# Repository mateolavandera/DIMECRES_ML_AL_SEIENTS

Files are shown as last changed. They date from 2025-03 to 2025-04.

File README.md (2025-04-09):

View this project on [CADLAB.io](https://cadlab.io/project/28988). 

# DIMECRES_ML_AL_SEIENTS
## Autors
- Mateo Lavandera Mulet (@mateolavandera)
- Alex Lara Bailon (@AlexLB4)

## Versió - v1.0 ## Curs - Assignatura de Disseny de PCBs amb KiCad - [Curs 2024-2025]

## Objectiu Descripció breu de l'objectiu del projecte.
L’objectiu del nostre projecte és dissenyar un sistema que sigui capaç d'executar correctament les diferents funcions que controlen uns seients elèctrics d’un cotxe qualsevol.

## Requisits i especificacions
→ 3 motors (posició, alçada, reclinació) amb els seus finals de carrera. 
→ Calefacció del seient. 
→ Sensor digital de cinturons. 
→ Memòria externa no volàtil per guardar posicions preprogramades.

## Diagrama de blocs (Afegiu una imatge del diagrama de blocs)
### Tercera versió (final)
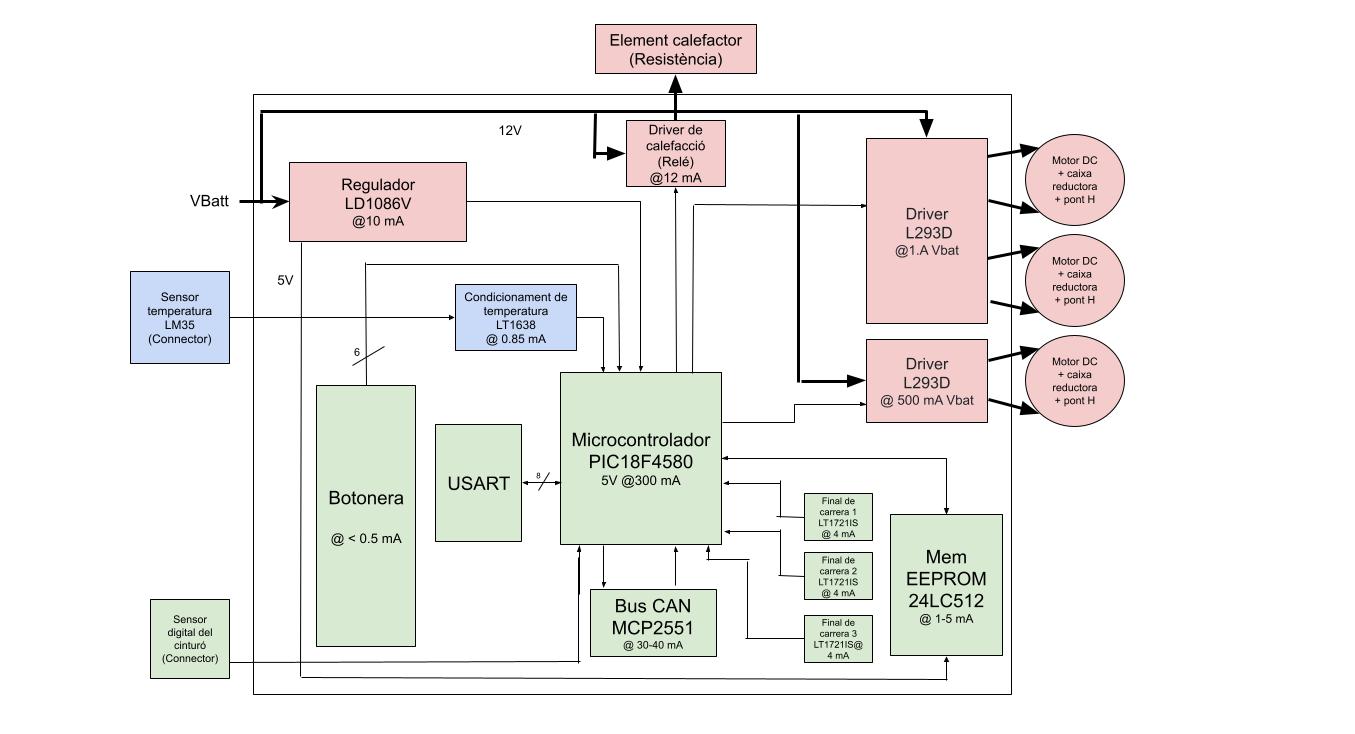
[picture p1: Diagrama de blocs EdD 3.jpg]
Diagrama de blocs


## Taula de components
| Descripció | Manufacturer Number | Package | Datasheet | Proveïdor | Unitats |
|---|---|---|---|---|---|
| Regulador Lineal 1.5 A  | LD1086V | TO-220 | [Enllaç](https://www.st.com/content/ccc/resource/technical/document/datasheet/53/db/00/58/09/98/4b/36/CD00001884.pdf/files/CD00001884.pdf/jcr:content/translations/en.CD000018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) | DigiKey | 1 |
| Microcontrolador PIC 8-bit 300mA | PIC18F4580-I/PT | 44-TQFP | [Enllaç](https://ww1.microchip.com/downloads/en/DeviceDoc/39637d.pdf) | DigiKey | 1 |
| DRV Bipolar 4.5-36 V  | L293D | 16-DIP | [Enllaç](https://www.st.com/content/ccc/resource/technical/document/datasheet/04/ac/22/f9/20/5d/43/a1/CD00000059.pdf/files/CD00000059.pdf/jcr:content/translations/en.CD000000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) | DigiKey | 2 |
| Memòria EEPROM I2C 5 mA  | 24LC512T-I/SN | 8-SOIC | [Enllaç](https://ww1.microchip.com/downloads/en/DeviceDoc/24AA512-24LC512-24FC512-512K-Bit-I2C-Serial-EEPROM-20001754Q.pdf) | DigiKey | 1 |
| Bus CAN (TRANSCEIVER) | TJA1051T	| 8-SOIC | [Enllaç](https://www.nxp.com/docs/en/data-sheet/TJA1051.pdf) | DigiKey | 1 |
| Final de carrera (Comparador) 5 V 4 mA  | LT1721 (Quad) | 16-SOIC | [Enllaç](https://www.analog.com/media/en/technical-documentation/data-sheets/17201fc.pdf) | DigiKey | 1 |
| Condicionador de temperatura (Amplificador) 30 mA  | LT6234 | 16-SSOP | [Enllaç](https://www.analog.com/media/en/technical-documentation/data-sheets/623345fc.pdf) | DigiKey | 1 |
| Sensor de temperatura 60uA | LM35 | 8-SOIC | [Enllaç](https://www.ti.com/lit/ds/symlink/lm35.pdf) | DigiKey | 1 |
| Relé 12mA | Omron G5V-1 | SIP-6 | [Enllaç](https://omronfs.omron.com/en_US/ecb/products/pdf/en-g5v_1.pdf) | DigiKey | 1 |

## Funcionalitats
- [ ] Funció 1
- [ ] Funció 2
- [ ] Funció 3

## Historial de canvis 
| Data | Autor | Branch | Descripció |
|---|---|---|---|
| 2025-03-22 | Alex | `main` | Modificació readme, concretament llistat d'elements |
| 2025-03-22 | Mateo | `main` | Correcció del diagrama de blocs |
| 2025-03-23 | Mateo | `main` | Primera versió de l'esquemàtic  |
| 2025-03-24 | Mateo | `main` | Segona versió de l'esquemàtic  |
| 2025-03-24 | Alex | `main` | Segona versió del llistat d'elements |
| 2025-03-25 | Mateo | `main` | Tercera versió de l'esquemàtic  |
| 2025-03-25 | Alex | `main` | Cuarta versió de l'esquemàtic  |
| 2025-03-25 | Alex | `main` | Segona versió del diagrama de blocs |
| 2025-03-25 | Alex | `main` | Simulacions LTSpice |
| 2025-03-25 | Alex | `main` | Assiganció net clases |
| 2025-03-26 | Alex | `main` | Canvi del comparador, modificació de diagrama i simulacions |
| 2025-03-26 | Mateo | `main` | Cinquena versió de l'esquemàtic |
| 2025-03-29 | Mateo | `main` | Modificació en taula de components: canvi opamp, afegir els sensors i relé |
| 2025-03-29 | Mateo | `main` | Sisena versió de l'esquemàtic |
| 2025-03-29 | Alex | `main` | Tercera versió diagrama de blocs |
| 2025-03-29 | Mateo | `main` | Primera versió prematura de layout |
| 2025-03-30 | Mateo | `main` | Segona versió prematura de layout |
| 2025-03-31 | Mateo | `main` | Tercera versió prematura de layout |
| 2025-03-31 | Mateo | `main` | Setena versió de l'esquemàtic |
| 2025-04-1 | Alex | `main` | Modificació components botonera a l'esquemàtic|
| 2025-04-1 | Alex | `main` | Nova simulació finals de carrera |
| 2025-04-1 | Mateo | `main` | Quarta versió de layout |
| 2025-04-6 | Alex | `main` | Afegir nova botonera a l'esquemàtic |
| 2025-04-7 | Alex | `main` | Cinquena versió layout |
| 2025-04-8 | Alex | `main` | Sisena versió layout |
| 2025-03-31 | Mateo | `main` | Vuitena versió de l'esquemàtic |

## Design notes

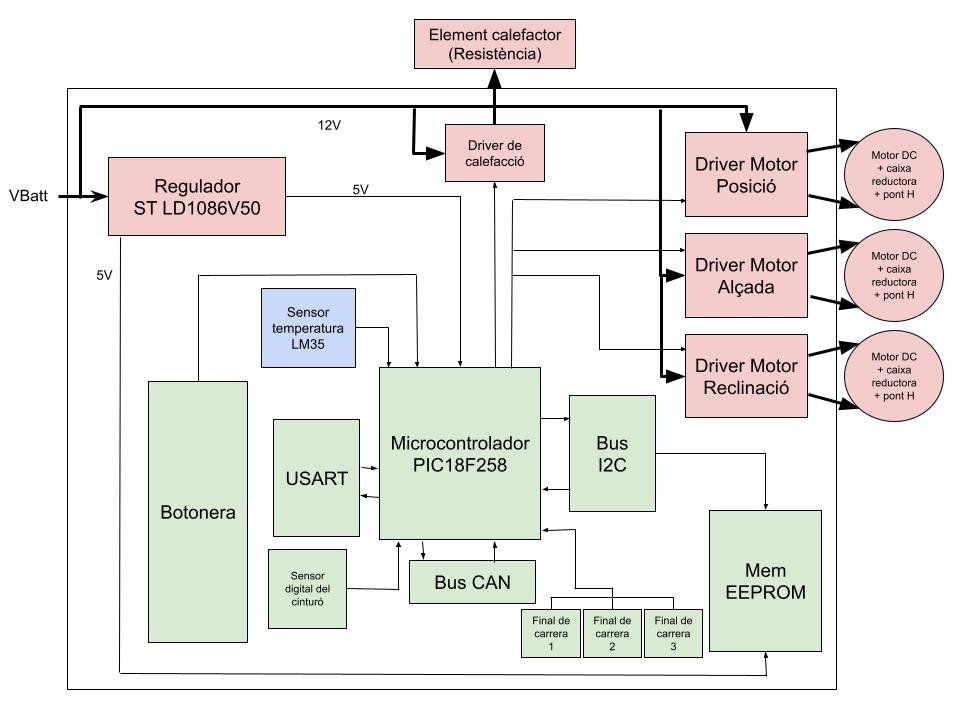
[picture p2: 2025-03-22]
Diagrama de blocs EdD (1).jpg

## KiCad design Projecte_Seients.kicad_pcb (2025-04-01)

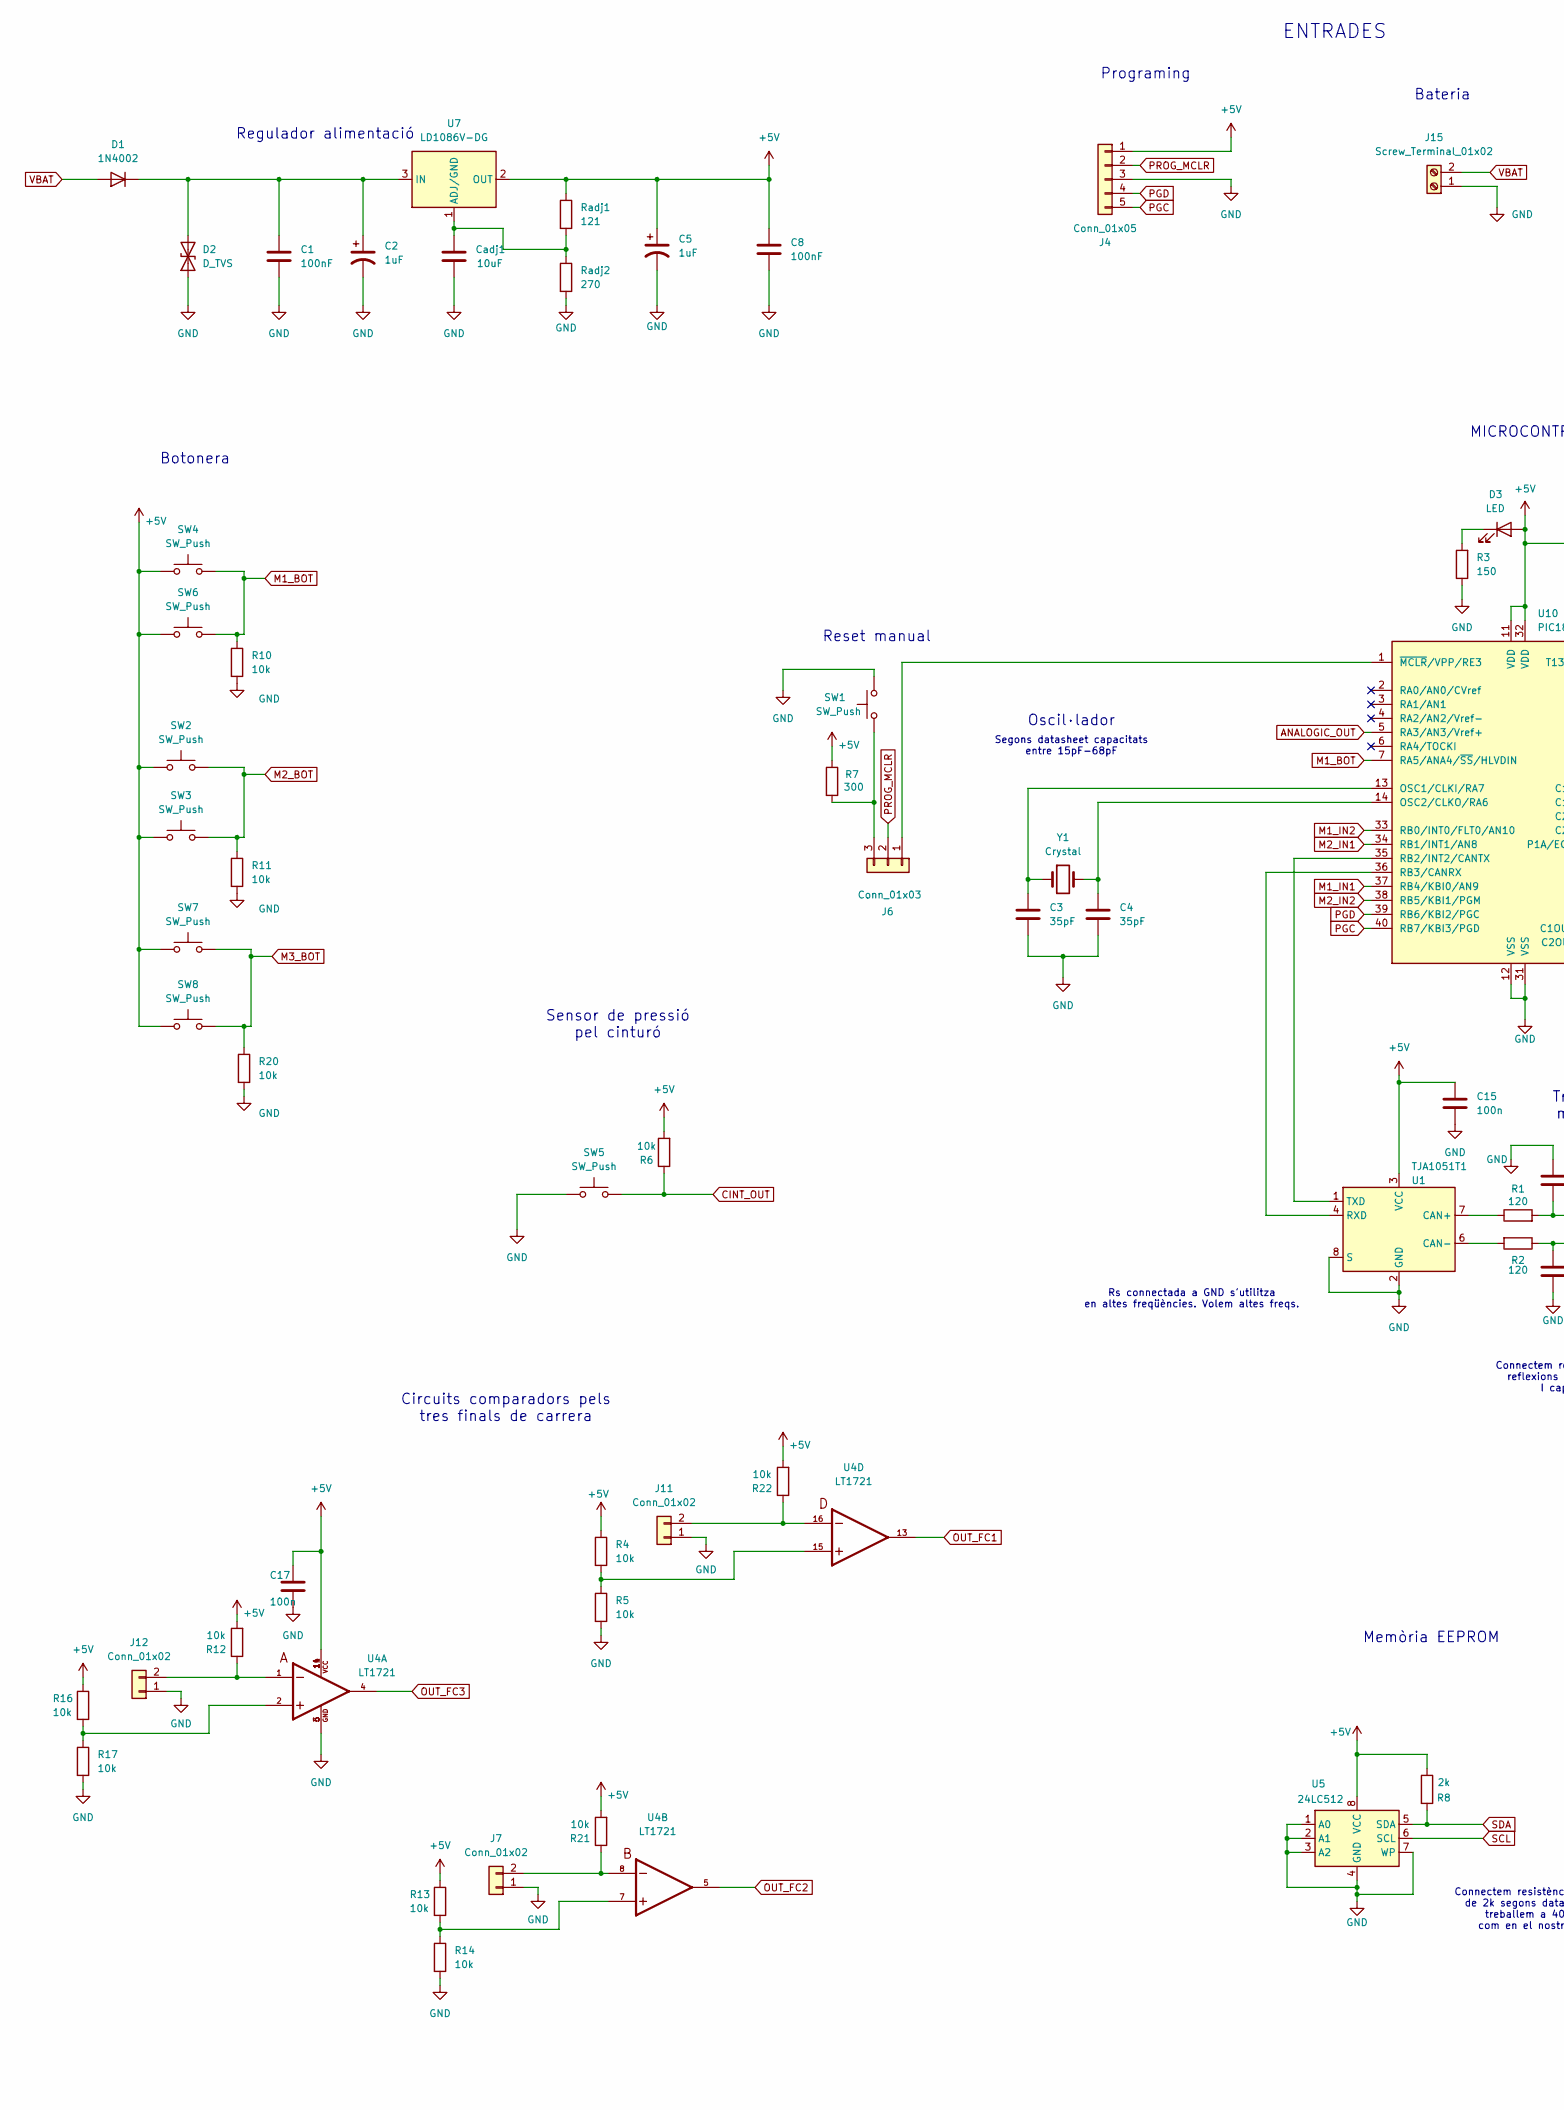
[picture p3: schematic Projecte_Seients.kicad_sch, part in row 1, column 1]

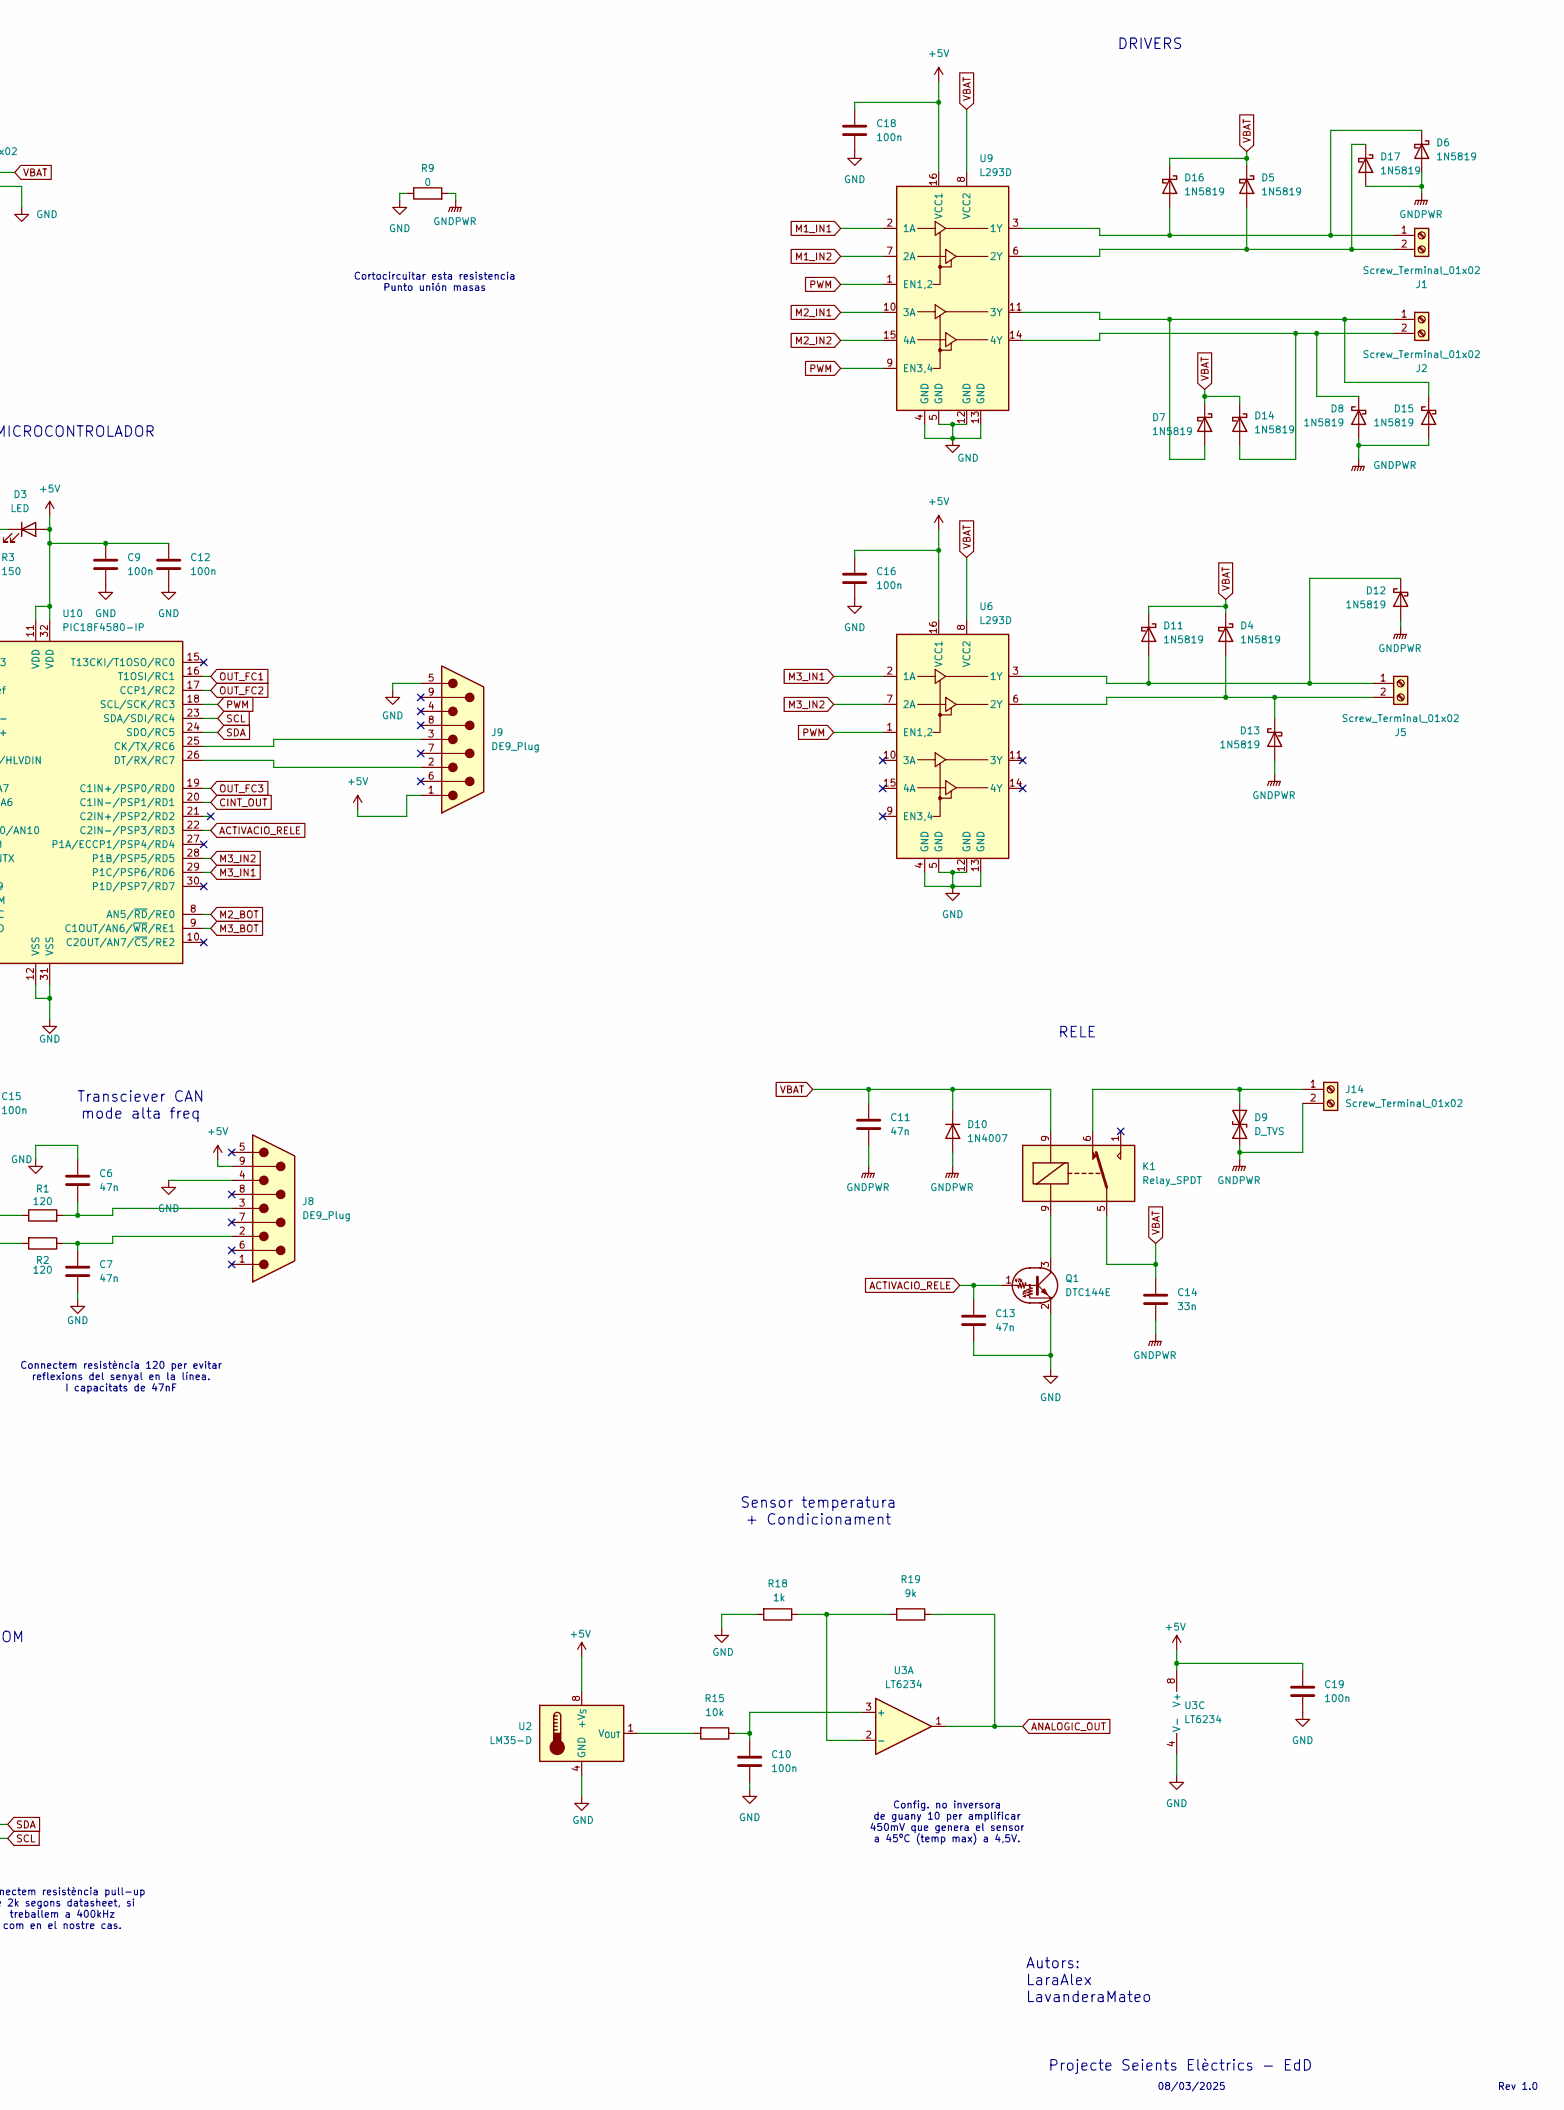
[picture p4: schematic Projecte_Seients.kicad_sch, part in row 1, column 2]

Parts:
C1, C8: 100nF; C_0805_2012Metric
C2, C5: 1uF; C_Radial_D5.0mm_H5.0mm_P2.00mm
C3, C4: 35pF; C_0805_2012Metric
C6, C7, C11, C13: 47n; C_0805_2012Metric
C9, C10, C12, C15, C16, C17, C18, C19: 100n; C_0805_2012Metric
C14: 33n; C_0805_2012Metric
Cadj1: 10uF; C_0805_2012Metric
D1: 1N4002; D_DO-41_SOD81_P10.16mm_Horizontal
D2, D9: D_TVS; D_DO-41_SOD81_P7.62mm_Horizontal
D3: LED; LED_0805_2012Metric
D4, D5, D6, D7, D8, D11, D12, D13, D14, D15, D16, D17: 1N5819; D_DO-41_SOD81_P10.16mm_Horizontal
D10: 1N4007; D_DO-41_SOD81_P10.16mm_Horizontal
J1, J2, J5, J14, J15: Screw_Terminal_01x02; TerminalBlock_MaiXu_MX126-5.0-02P_1x02_P5.00mm
J4: Conn_01x05; PinHeader_1x05_P2.54mm_Vertical
J6: Conn_01x03; PinHeader_1x03_P2.54mm_Vertical
J7, J11, J12: Conn_01x02; PinHeader_1x02_P2.54mm_Vertical
J8, J9: DE9_Plug; DSUB-9_Male_Vertical_P2.77x2.84mm
K1: Relay_SPDT; Relay_SPDT_Omron_G5V-1
Q1: DTC144E; TO-220-3_Vertical
R1, R2: 120; R_1206_3216Metric
R3: 150; R_0805_2012Metric
R4, R5, R13, R14, R16, R17: 10k; R_1206_3216Metric
R6, R10, R11, R12, R15, R20, R21, R22: 10k; R_0805_2012Metric
R7: 300; R_1206_3216Metric
R8: 2k; R_1206_3216Metric
R9: 0; R_Axial_DIN0204_L3.6mm_D1.6mm_P5.08mm_Horizontal
R18: 1k; R_0805_2012Metric
R19: 9k; R_0805_2012Metric
Radj1: 121; R_0815_2038Metric
Radj2: 270; R_0815_2038Metric
SW1, SW2, SW3, SW4, SW5, SW6, SW7, SW8: SW_Push; SW_2-1437565-7
TJA1051T1: U1; SOIC-8_3.9x4.9mm_P1.27mm
U2: LM35-D; SOIC-8_3.9x4.9mm_P1.27mm
U3: LT6234; SOIC-8_3.9x4.9mm_P1.27mm
U4: LT1721; SOIC-16_4.55x10.3mm_P1.27mm
U5: 24LC512; SO-8_3.9x4.9mm_P1.27mm
U6, U9: L293D; DIP-16_W7.62mm
U7: LD1086V-DG; HuellaDis
U10: PIC18F4580-IP; DIP-40_W15.24mm_SMD
Y1: Crystal; Crystal_HC49-U_Vertical

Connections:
+5V: C5.1, C8.1, C9.2, C12.2, C15.2, C16.2, C17.2, C18.2, C19.2, D3.2 (A), J4.1, J8.9, J9.1, R4.1, R6.2, R7.1, R8.1, R12.2, R13.1, R16.1, R21.2, R22.2, Radj1.1, SW2.1, SW3.1, SW4.1, SW6.1, SW7.1, SW8.1, TJA1051T1.3 (VCC), U2.8 (+V_{S}), U3.8 (V+), U4.11, U4.14, U5.8 (VCC), U6.16 (VCC1), U7.2 (OUT), U9.16 (VCC1), U10.11 (VDD), U10.32 (VDD)
ACTIVACIO_RELE: C13.2, Q1.1 (B), U10.22 (C2IN-/PSP3/RD3)
ANALOGIC_OUT: R19.1, U3.1, U10.5 (RA3/AN3/Vref+)
CINT_OUT: R6.1, SW5.2, U10.20 (C1IN-/PSP1/RD1)
GND: C1.2, C2.2, C3.2, C4.2, C5.2, C6.1, C7.1, C8.2, C9.1, C10.1, C12.1, C13.1, C15.1, C16.1, C17.1, C18.1, C19.1, Cadj1.2, D2.1 (A1), J4.3, J7.1, J8.4, J9.5, J11.1, J12.1, J15.1, Q1.2 (E), R3.1, R5.2, R9.1, R10.2, R11.2, R14.2, R17.2, R18.2, R20.2, Radj2.2, SW1.2, SW5.1, TJA1051T1.2 (GND), TJA1051T1.8 (S), U2.4 (GND), U3.4 (V-), U4.3, U4.6, U5.1 (A0), U5.2 (A1), U5.3 (A2), U5.4 (GND), U5.7 (WP), U6.4 (GND), U6.5 (GND), U6.12 (GND), U6.13 (GND), U9.4 (GND), U9.5 (GND), U9.12 (GND), U9.13 (GND), U10.12 (VSS), U10.31 (VSS)
GNDPWR: C11.1, C14.1, D6.2 (A), D8.2 (A), D9.1 (A1), D10.2 (A), D12.2 (A), D13.2 (A), D15.2 (A), D17.2 (A), J14.2, R9.2
M1_BOT: R10.1, SW4.2, SW6.2, U10.7 (RA5/ANA4/~SS/HLVDIN)
M1_IN1: U9.2 (1A), U10.37 (RB4/KBI0/AN9)
M1_IN2: U9.7 (2A), U10.33 (RB0/INT0/FLT0/AN10)
M2_BOT: R11.1, SW2.2, SW3.2, U10.8 (AN5/~RD/RE0)
M2_IN1: U9.10 (3A), U10.34 (RB1/INT1/AN8)
M2_IN2: U9.15 (4A), U10.38 (RB5/KBI1/PGM)
M3_BOT: R20.1, SW7.2, SW8.2, U10.9 (C1OUT/AN6/~WR/RE1)
M3_IN1: U6.2 (1A), U10.29 (P1C/PSP6/RD6)
M3_IN2: U6.7 (2A), U10.28 (P1B/PSP5/RD5)
unnamed: C6.2, J8.3, R1.2
unnamed: C7.2, J8.2, R2.1
unnamed: C1.1, C2.1, D1.1 (K), D2.2 (A2), U7.3 (IN)
unnamed: D3.1 (K), R3.2
unnamed: D9.2 (A2), J14.1, K1.6
unnamed: D11.2 (A), D12.1 (K), J5.1, U6.3 (1Y)
unnamed: D4.2 (A), D13.1 (K), J5.2, U6.6 (2Y)
unnamed: D8.1 (K), D14.2 (A), J2.2, U9.14 (4Y)
unnamed: D7.2 (A), D15.1 (K), J2.1, U9.11 (3Y)
unnamed: D6.1 (K), D16.2 (A), J1.1, U9.3 (1Y)
unnamed: D5.2 (A), D17.1 (K), J1.2, U9.6 (2Y)
unnamed: J6.1, U10.1 (~MCLR/VPP/RE3)
unnamed: J6.3, R7.2, SW1.1
unnamed: J7.2, R21.1, U4.8
unnamed: J11.2, R22.1, U4.16
unnamed: J12.2, R12.1, U4.1
unnamed: R4.2, R5.1, U4.15
unnamed: R13.2, R14.1, U4.7
unnamed: R16.2, R17.1, U4.2
unnamed: R1.1, TJA1051T1.7 (CAN+)
unnamed: R2.2, TJA1051T1.6 (CAN-)
unnamed: TJA1051T1.4 (RXD), U10.36 (RB3/CANRX)
unnamed: TJA1051T1.1 (TXD), U10.35 (RB2/INT2/CANTX)
unnamed: R15.2, U2.1 (V_{OUT})
unnamed: C10.2, R15.1, U3.3 (+)
unnamed: R18.1, R19.2, U3.2 (-)
unnamed: Cadj1.1, Radj1.2, Radj2.1, U7.1 (ADJ/GND)
unnamed: J9.3, U10.25 (CK/TX/RC6)
unnamed: J9.2, U10.26 (DT/RX/RC7)
unnamed: C3.1, U10.13 (OSC1/CLKI/RA7), Y1.1
unnamed: C4.1, U10.14 (OSC2/CLKO/RA6), Y1.2
OUT_FC1: U4.13, U10.16 (T1OSI/RC1)
OUT_FC2: U4.5, U10.17 (CCP1/RC2)
OUT_FC3: U4.4, U10.19 (C1IN+/PSP0/RD0)
PGC: J4.5, U10.40 (RB7/KBI3/PGD)
PGD: J4.4, U10.39 (RB6/KBI2/PGC)
PROG_MCLR: J4.2, J6.2
PWM: U6.1 (EN1,2), U9.1 (EN1,2), U9.9 (EN3,4), U10.18 (SCL/SCK/RC3)
SCL: U5.6 (SCL), U10.23 (SDA/SDI/RC4)
SDA: R8.2, U5.5 (SDA), U10.24 (SDO/RC5)

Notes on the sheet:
Segons datasheet capacitats entre 15pF-68pF
Bateria
Transciever CAN mode alta freq
Connectem resistència pull-up de 2k segons datasheet, si treballem a 400kHz com en el nostre cas.
Sensor temperatura + Condicionament
Programing
Cortocircuitar esta resistencia Punto unión masas
Projecte Seients Elèctrics - EdD
Sensor de pressió pel cinturó
Autors: LaraAlex LavanderaMateo
Rs connectada a GND s'utilitza en altes freqüències. Volem altes freqs.
Regulador alimentació
Botonera
Circuits comparadors pels tres finals de carrera
Rev 1.0
08/03/2025
Memòria EEPROM
RELE
Reset manual
Oscil·lador
Config. no inversora de guany 10 per amplificar 450mV que genera el sensor a 45ºC (temp max) a 4,5V.
ENTRADES
Connectem resistència 120 per evitar reflexions del senyal en la línea. I capacitats de 47nF
MICROCONTROLADOR
DRIVERS

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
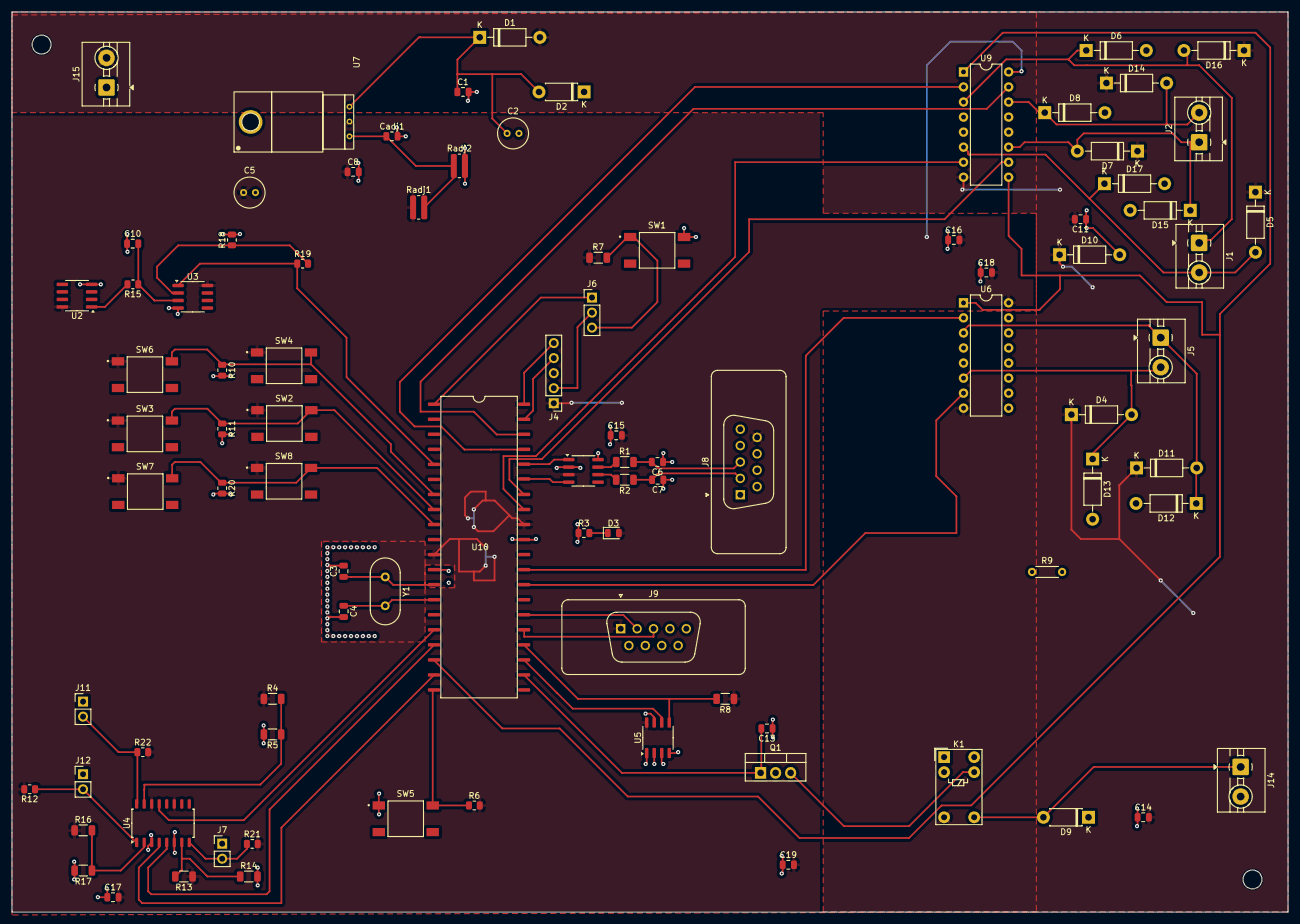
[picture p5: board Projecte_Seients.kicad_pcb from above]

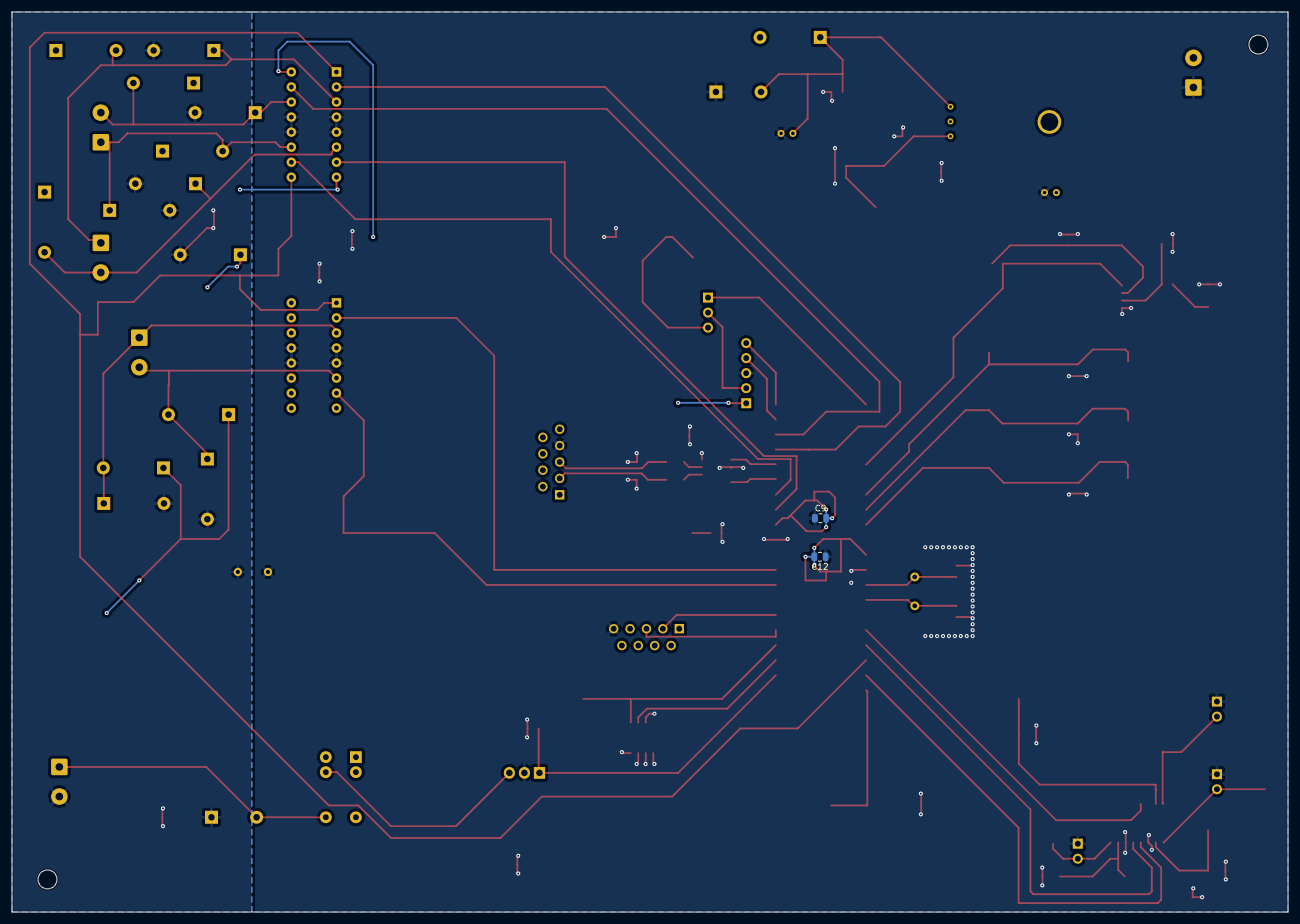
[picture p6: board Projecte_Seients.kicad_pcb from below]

Board: 2 copper layers, 215.5 x 152.0 mm, 93 parts (2 on the bottom side), 57 nets.
